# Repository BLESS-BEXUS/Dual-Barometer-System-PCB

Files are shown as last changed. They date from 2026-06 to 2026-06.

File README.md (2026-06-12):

<p align="center">
    <br>
    <a href="https://bless-bexus.es">
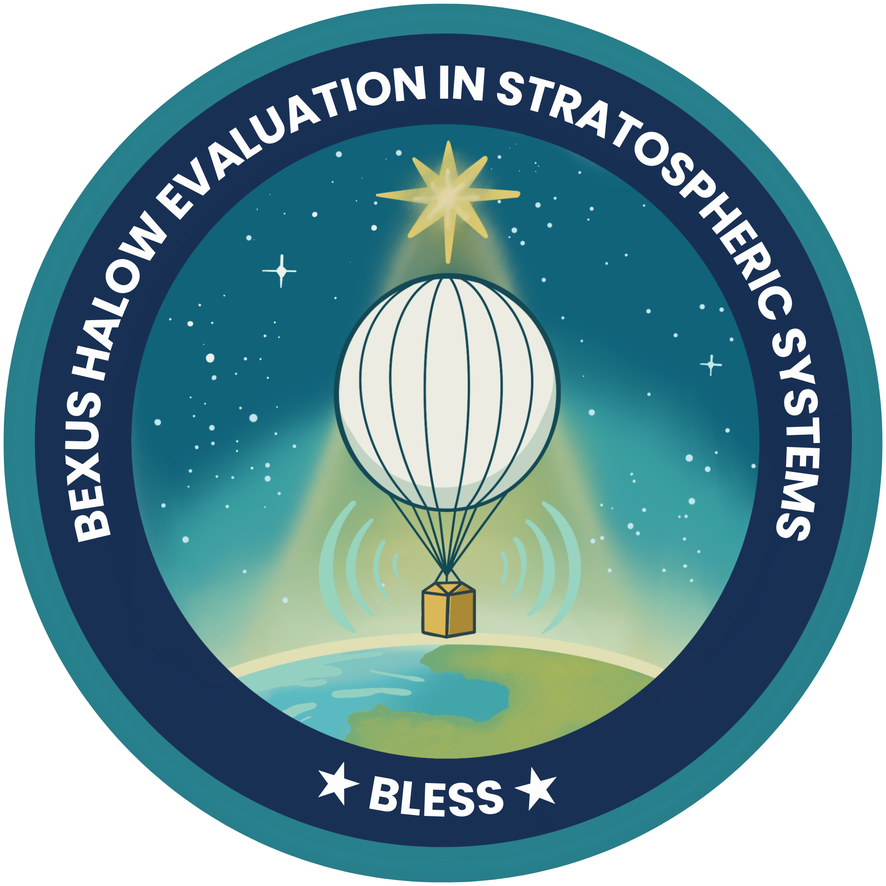
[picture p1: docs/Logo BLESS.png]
BLESS Logo
        
    </a>
</p>
<h1 align="center">Dual-Barometer System</h1>
<p align="center">
A compact PCB designed to provide wide-range pressure measurement, redundant sensing and onboard calibration for embedded systems where reliability, accuracy and easy integration are key.
</p>

<p align="center">
    
    
    <br>
    <a href="https://rexusbexus.net/">
        
    </a>
</p>

---

### Overview

The main goal of this PCB is to improve the reliability and accuracy of pressure measurement in embedded sensing systems.

It is especially useful in applications where pressure conditions may vary significantly during operation and where a single commercial sensor may not provide enough range, resolution or calibration stability.

The board is designed to support:

- Wide-range pressure measurement.
- Redundant pressure sensing.
- Altitude estimation.
- Sensor cross-validation.
- Onboard calibration storage.
- Easy integration with a main controller.

### Main Features

- Dual-barometer architecture.
- TE MS5803-01BA high-resolution pressure sensor.
- Amphenol NPA-730B low-pressure backup sensor.
- Shared I2C communication bus.
- Onboard Microchip 24LC02B EEPROM.
- Storage of board-specific calibration coefficients.
- Plug-and-play calibration approach.
- Compact PCB for embedded sensing applications.
- Custom KiCad symbols, footprints and 3D models.

---

<h3 align="center">Contributing</h3>

<p align="center">
·
    <a href="./CODE_OF_CONDUCT.md">Code of Conduct</a>
    ·
    <a href="./CONTRIBUTING.md">Contributing Guide</a>
    ·
</p>

<p align="center">We welcome collaboration from the aerospace and software community. For major changes or data inquiries, please open an issue first.</p>

<h3 align="center">License</h3>

<pre align="center">Copyright © 2025-2026 The BLESS Project Team<br><br>This Source Code Form is subject to the terms of the Mozilla Public<br>License, v. 2.0. If a copy of the MPL was not distributed with this<br>file, You can obtain one at http://mozilla.org/MPL/2.0/.</pre>

<h3 align="center">Credits & Team</h3>

<p align="center">Supported by the REXUS/BEXUS Program and our generous sponsors.</p>
<p align="center">
    <a href="https://github.com/BLESS-BEXUS/Dual-Barometer-System-PCB/graphs/contributors">
        
    </a>
</p>

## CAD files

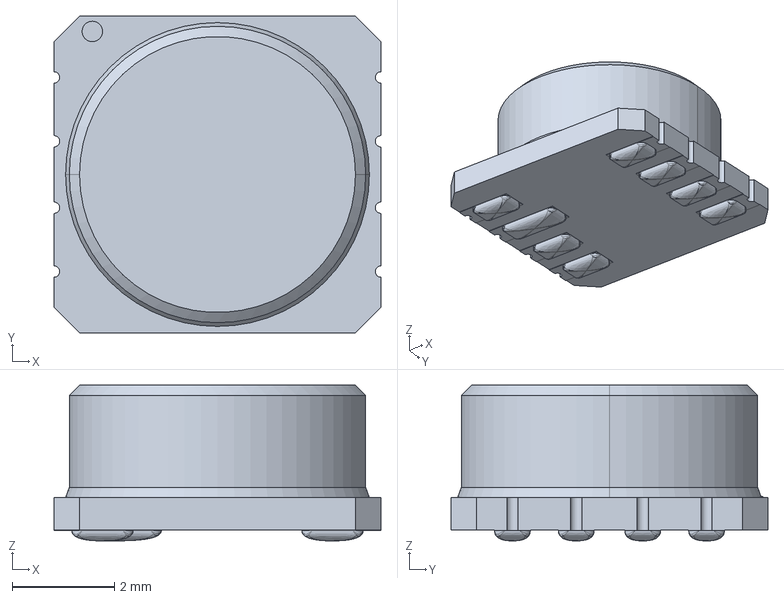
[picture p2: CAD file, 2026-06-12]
STEPS/MS580314BA01-00.step
6.40 x 6.20 x 3.05 mm

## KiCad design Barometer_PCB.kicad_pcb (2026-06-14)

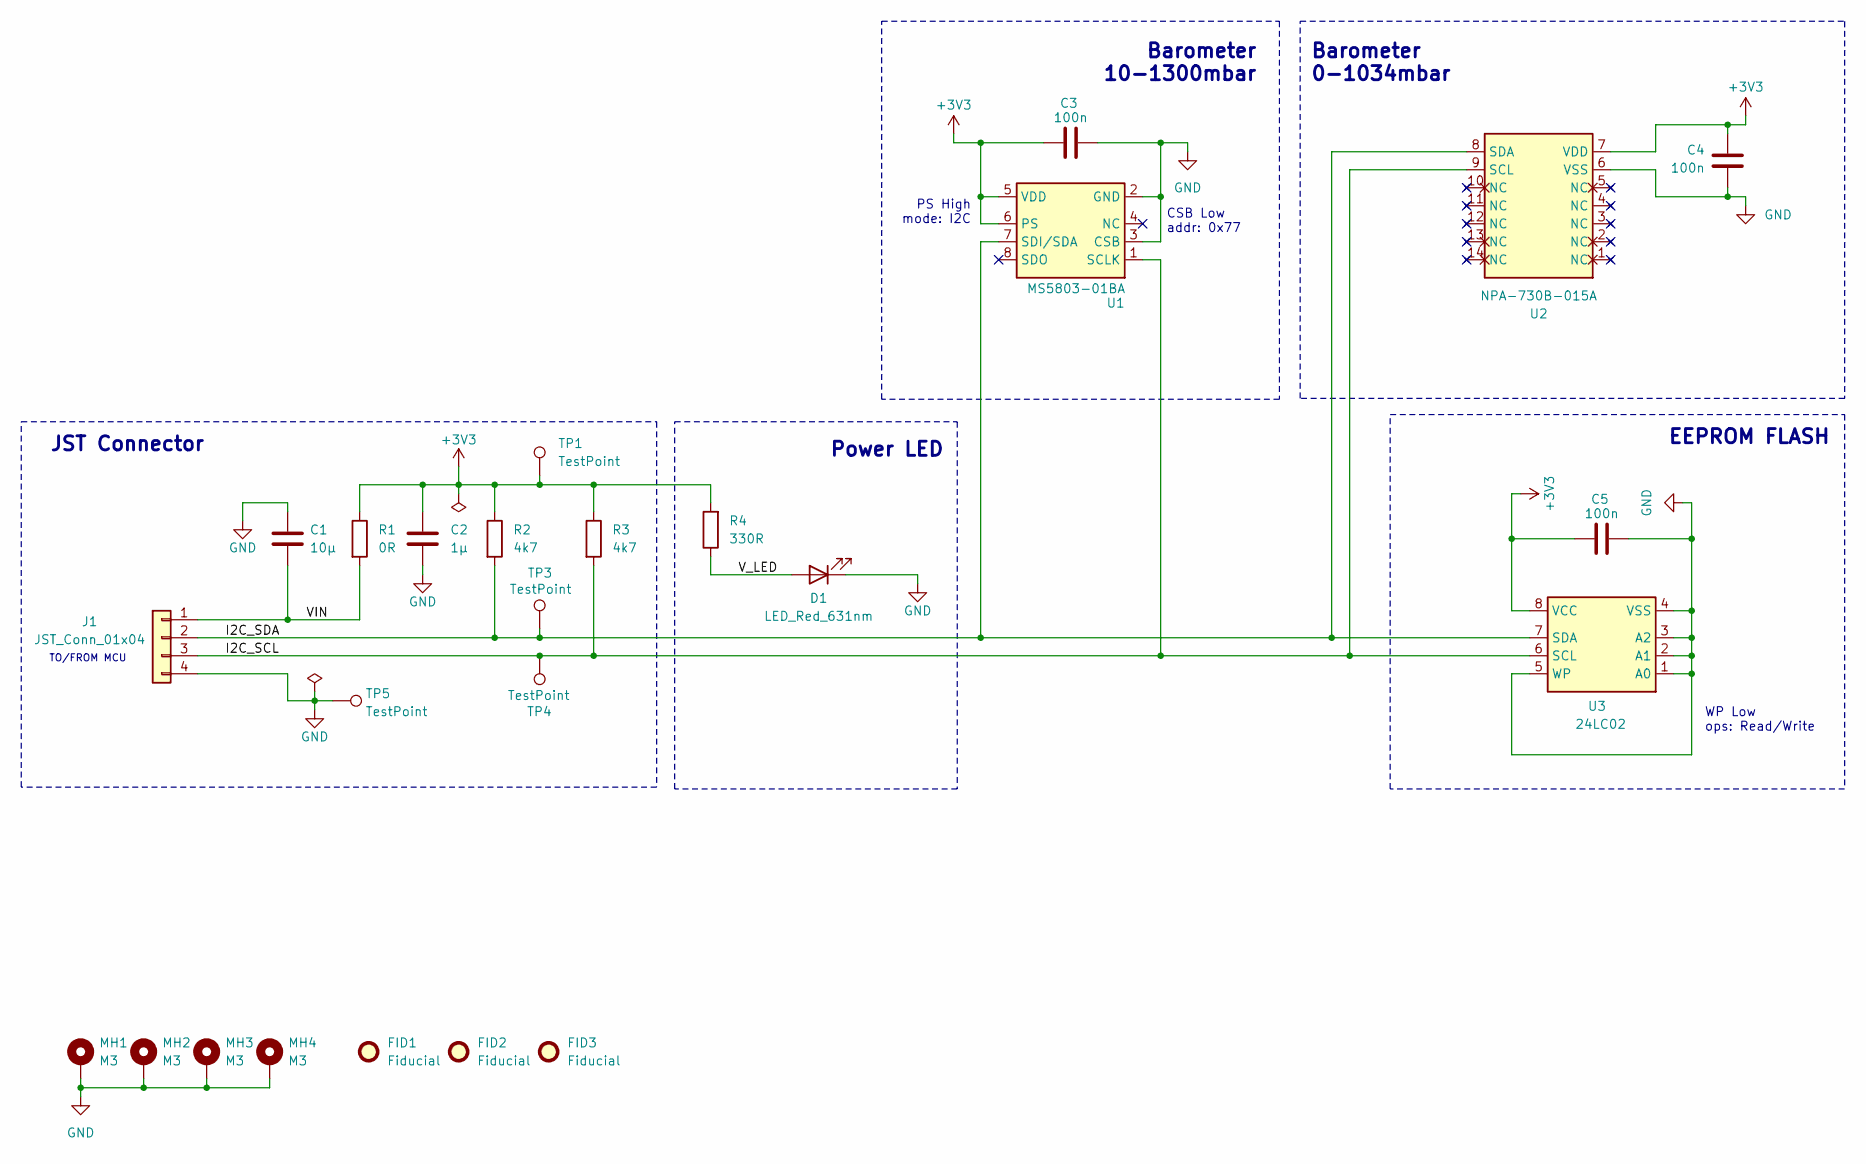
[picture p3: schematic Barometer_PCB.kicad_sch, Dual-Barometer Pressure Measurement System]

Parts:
C1: 10µ; C_1206_3216Metric; Manufacturer Part Number CGA5L1X7R1C106K160AC; LCSC C2168241
C2: 1µ; C_0805_2012Metric; Manufacturer Part Number KGM21AR71C105JU; LCSC C20219896
C3, C4, C5: 100n; C_0805_2012Metric; Manufacturer Part Number GCD21BR71H104KA01K; LCSC C21025875
D1: LED_Red_631nm; LED_0603_1608Metric; Manufacturer Part Number LTST-C190KRKT; LCSC C94869
FID1, FID2, FID3: Fiducial; Fiducial_1mm_Mask2mm
J1: JST_Conn_01x04; JST_SH_BM04B-SRSS-TB_1x04-1MP_P1.00mm_Vertical; Manufacturer Part Number BM04B-SRSS-TB(LF)(SN); LCSC C160390
MH1, MH2, MH3, MH4: M3; MountingHole_3.2mm_M3_Pad_Via
R1: 0R; R_0603_1608Metric; Manufacturer Part Number RC0603JR-070RL; LCSC C95177
R2, R3: 4k7; R_0805_2012Metric; Manufacturer Part Number AC0805JR-134K7L; LCSC C6457914
R4: 330R; R_0603_1608Metric; Manufacturer Part Number CR0603-FX-3300ELF; LCSC C2077087
TP1, TP3, TP4, TP5: TestPoint; TestPoint_Pad_D1.0mm
U1: MS5803-01BA; Manufacturer Part Number MS580301BA01-00; LCSC C5166409
U2: NPA-730B-015A; SOIC-14W_7.5x9mm_P1.27mm; Manufacturer Part Number NPA-730B-015A; LCSC C3253841
U3: 24LC02; SOIC-8_3.9x4.9mm_P1.27mm; Manufacturer Part Number 24LC02B-I/SN; LCSC C1348870

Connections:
+3V3: C2.1, C3.1, C4.1, C5.1, R1.1, R2.1, R3.1, R4.2, TP1.1, U1.5 (VDD), U1.6 (PS), U2.7 (VDD), U3.8 (VCC)
/I2C_SCL: J1.3, R3.2, TP4.1, U1.1 (SCLK), U2.9 (SCL), U3.6 (SCL)
/I2C_SDA: J1.2, R2.2, TP3.1, U1.7 (SDI/SDA), U2.8 (SDA), U3.7 (SDA)
/VIN: C1.1, J1.1, R1.2
/V_LED: D1.2 (A), R4.1
GND: C1.2, C2.2, C3.2, C4.2, C5.2, D1.1 (K), J1.4, MH1.1, MH2.1, MH3.1, MH4.1, TP5.1, U1.2 (GND), U1.3 (CSB), U2.6 (VSS), U3.1 (A0), U3.2 (A1), U3.3 (A2), U3.4 (VSS), U3.5 (WP); also elsewhere on the board

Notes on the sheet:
Barometer 10-1300mbar
Power LED
PS High mode: I2C
TO/FROM MCU
JST Connector
EEPROM FLASH
Barometer 0-1034mbar
WP Low ops: Read/Write
CSB Low addr: 0x77

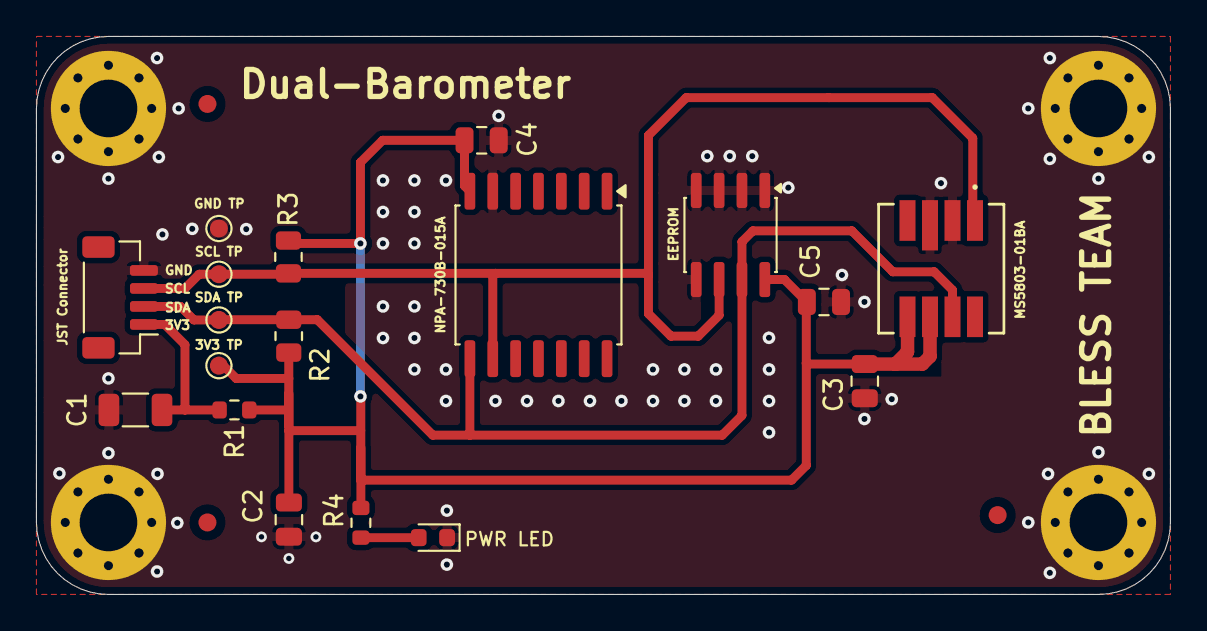
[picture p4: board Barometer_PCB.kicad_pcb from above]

Board: 2 copper layers, 63.0 x 31.0 mm, 25 parts (0 on the bottom side), 6 nets.

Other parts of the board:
TP1#2: TestPoint; TestPoint_Pad_D1.0mm

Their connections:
GND: TP1#2.1; also elsewhere on the board

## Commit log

2026-06-12 Add initial barometer PCB KiCad project
    [Barometer_PCB.kicad_pcb, Barometer_PCB.kicad_sch]
2026-06-12 Add MS5803 footprint, symbol libraries and STEP model
    [MS580314BA01-00.step]
2026-06-14 Fix DRC checks for GND
    [Barometer_PCB.kicad_pcb]
2026-06-14 JST pin and test point texts
    [Barometer_PCB.kicad_pcb]
